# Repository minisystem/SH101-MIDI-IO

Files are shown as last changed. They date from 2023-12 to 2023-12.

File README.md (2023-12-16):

# SH101 MIDI IO
PCB assembly for TRS-DIN MIDI connections to SH-101

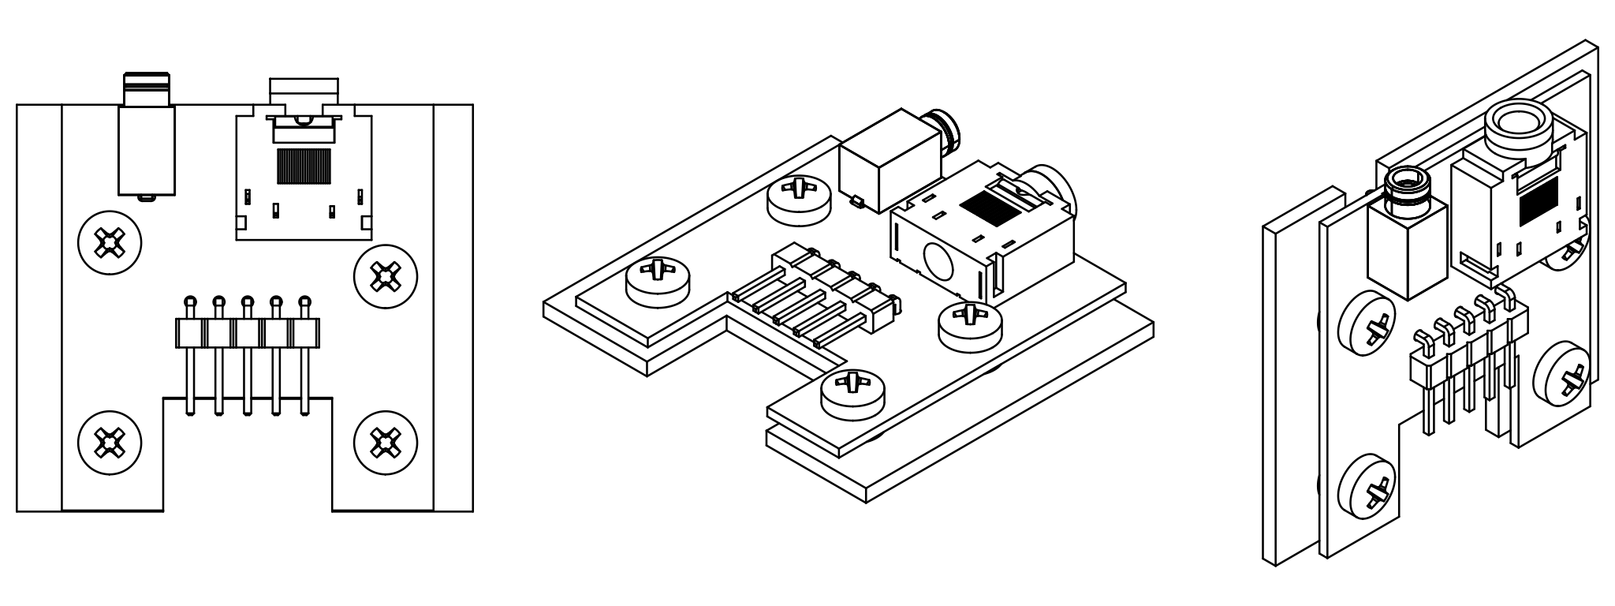
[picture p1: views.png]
pcb assembly


## Overview
[Tubbutec](https://tubbutec.de/sh-1oh1/) make an amazing upgrade kit for the Roland SH-101 that replaces the original CPU, adding MIDI, some new modulation sources, and an enhanced sequencer and arpeggiator. The kit comes with a pair of MIDI jacks that can be mounted by drilling holes in the enclosure, or concealed in the battery compartment. This respository contains the design files to build a TRS adapter board to replace the SH-101's MODULATION GRIP PCB, which allows the use of Type A TRS-MIDI cables. The MIDI IN uses the 3.5 MM jack and the MIDI OUT uses the 2.5 MM jack. To get the jacks to the right height, a PCB sandwich is required with 1.5 MM spacers. I used SMT M3 spacers, but a regular PCB spacer of the right height should work as well. There's enough room in the enclsoure to leave the original MODULATION GRIP PCB, so it does not need to be disconnected or removed. The jack PCB needs to be 1 MM thick, and the spacer PCB needs to be 1.6 MM thick.

The project was designed in Kicad 6.0. The BOM and pos files for PCBA of the modulation grip spacer PCB with SMT spacers have been formatted for the JLC PCBA service.

## BOM

| Part Ref | Description | Part No |
| --- | --- | --- |
| J1 | 3.5 MM JACK | CUI SJ1-3523N |
| J2 | 2.5 MM JACK | CUI SJ1-2503A |
| J3 | 5 POS HEADER | 0.100" RIGHT ANGLE |
| SM1-4 | 1.5 MM M3 SPACER | SMTSO3015CTJ |

You'll also need a Type A 3.5 MM TRS MIDI cable and a 2.5 MM TRS MIDI cable if you want access to MIDI OUT data. The 2.5 MM TRS to MIDI cable isn't as widely availabe, but is used by a lot of IK Multimedia iRig series products.

## PCBs

The PCB fabrication files are in the [gerbers](/gerbers/) folder. _SH101_IO.zip_ contains the gerber files for the 1 MM thick jack board and _SH101_MOD_GRIP_BOARD.zip_ contains the gerbers for the 1.6 MM modulation grip spacer board. 

## Assembly

Once assembled, the PCB sandwich slides into guide slots of the plastic enclosure. Tape the original modulation grip jack board to the side of the enclosure. Use a 5 conductor connector assembly, crimp contacts, 0.100" pitch (TE 5-103975-4 or equivalent). Refer to the schematic and PCB markings for wiring order.

The Type A TRS wiring is as follows:

MIDI 4 (source) > RING

MIDI 2 (shield) > SLEEVE

MIDI 5 (sink) > TIP

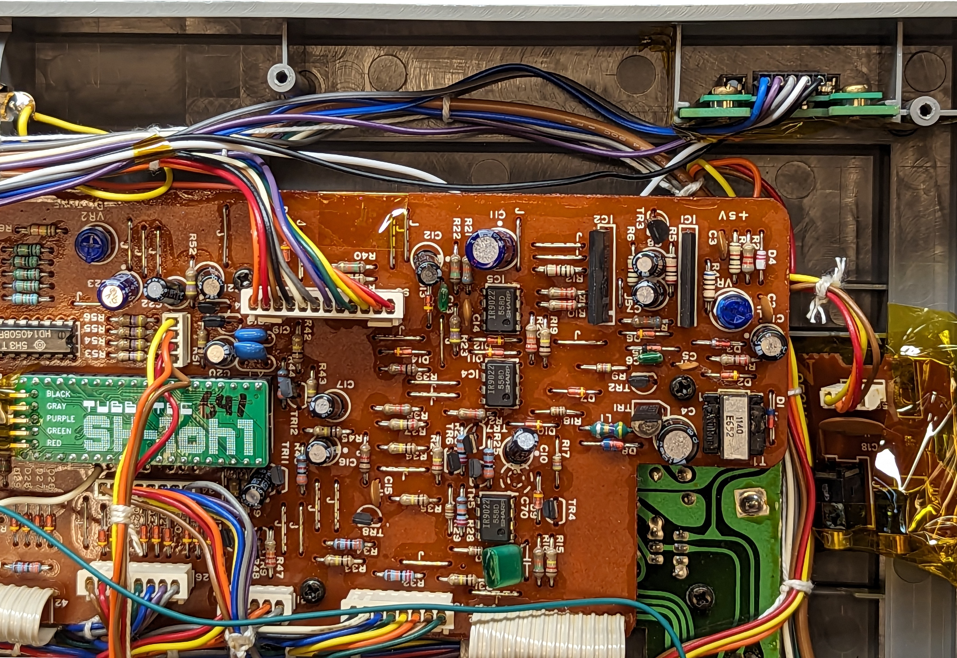
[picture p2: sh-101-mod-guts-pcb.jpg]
pcb guts


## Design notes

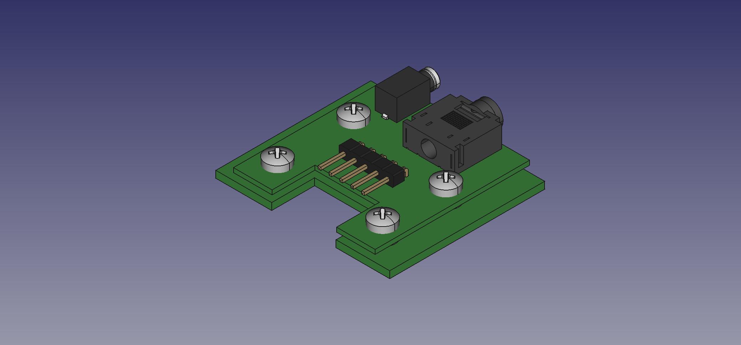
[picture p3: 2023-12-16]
3d/orthoview.jpeg

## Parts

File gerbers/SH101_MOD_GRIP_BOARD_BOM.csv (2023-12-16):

Comment | Designator | Footprint | LCSC
SMTSO3015CTJ | SP1,SP2,SP3,SP4 | MyModules:SMTSO3060CTJ | C2915632

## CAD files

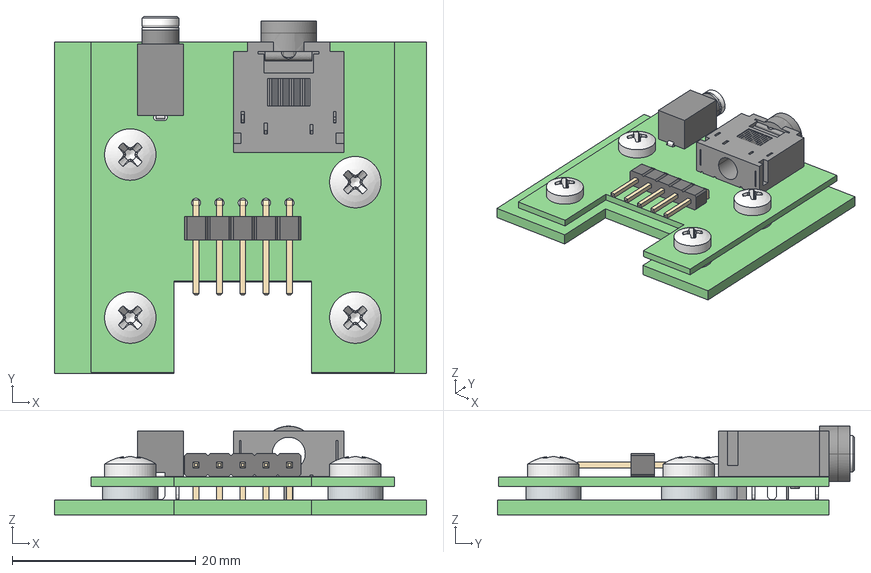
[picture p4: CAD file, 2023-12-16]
3d/assembly.step
40.5 x 38.9 x 9.66 mm
SH101_IO PCB
SH101_MOD_GRIP_BOARD PCB
M3x4-Screw
M3x4-Screw007
M3x4-Screw005
M3x4-Screw006

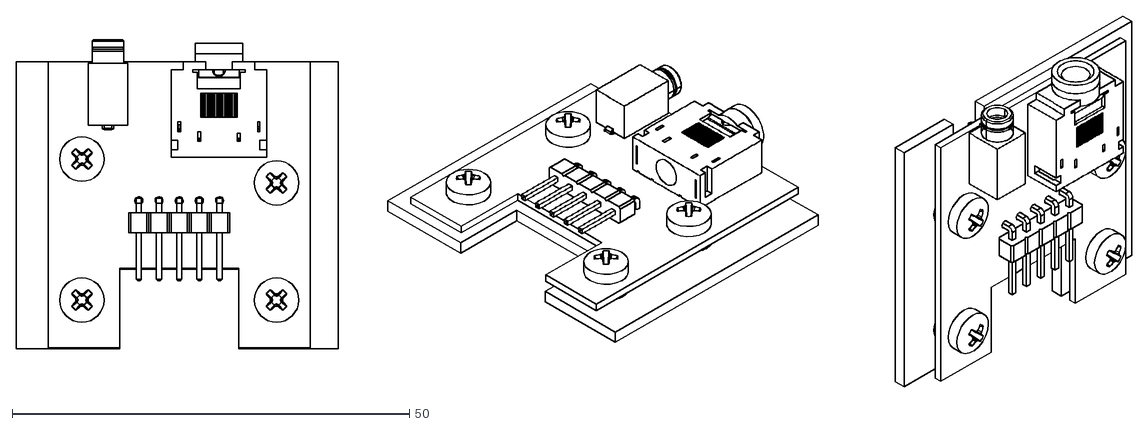
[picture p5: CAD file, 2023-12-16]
3d/views.dxf
140.4 x 46.7

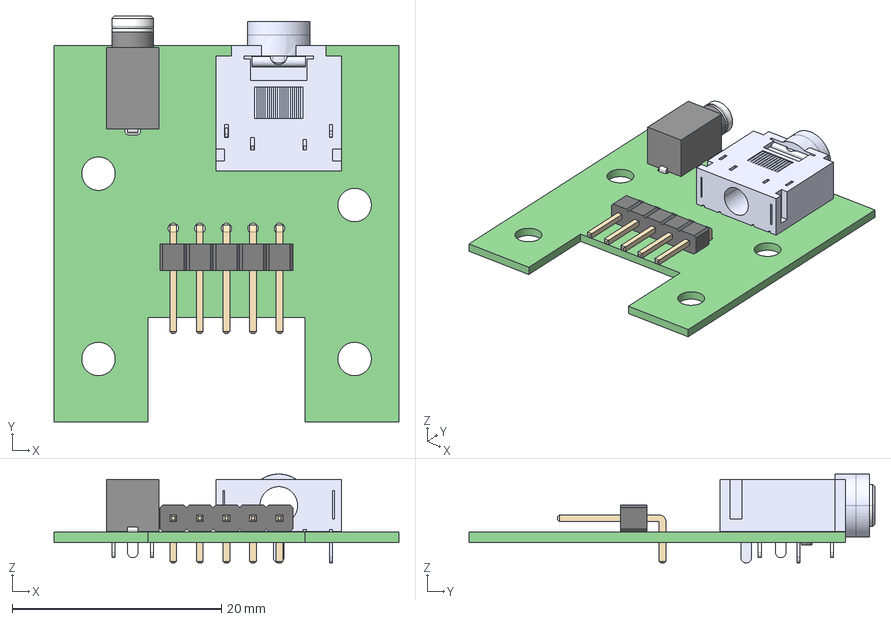
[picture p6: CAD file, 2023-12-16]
3d/SH101_IO.step
33.0 x 38.8 x 8.51 mm
SH101_IO PCB

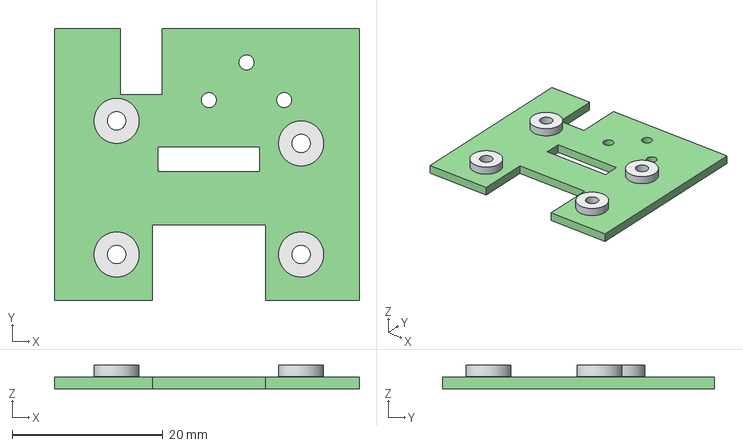
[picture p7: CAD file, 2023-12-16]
3d/SH101_MOD_GRIP_BOARD.step
40.5 x 36.1 x 3.15 mm
SH101_MOD_GRIP_BOARD PCB

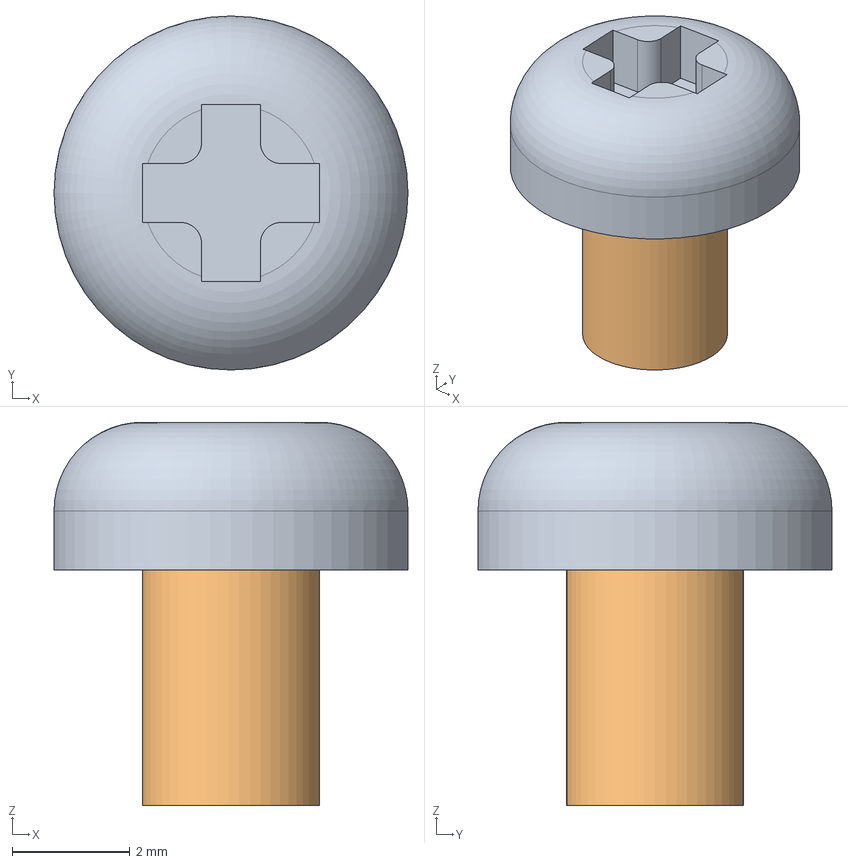
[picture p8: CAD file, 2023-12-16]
3d/M3x4MM.FCStd
6.00 x 6.00 x 6.50 mm

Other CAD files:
3d/SH101_IO_MOD_GRIP_BOARD.FCStd

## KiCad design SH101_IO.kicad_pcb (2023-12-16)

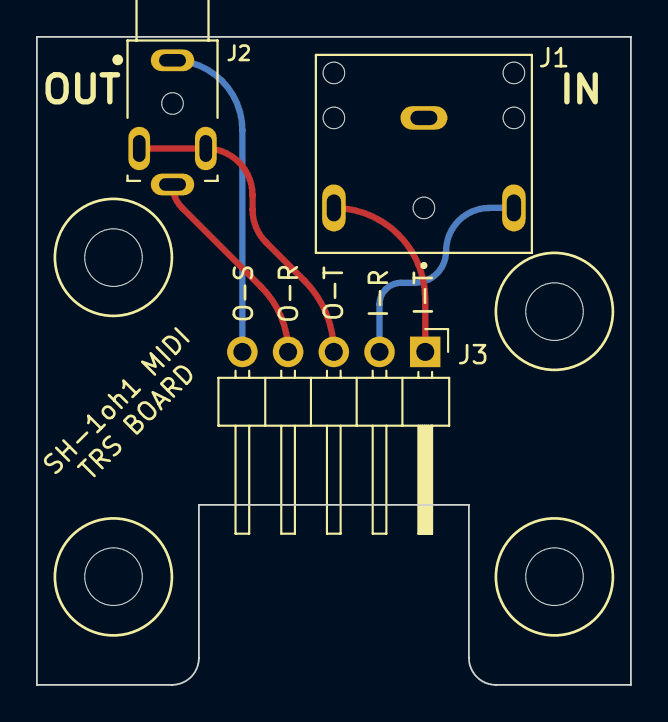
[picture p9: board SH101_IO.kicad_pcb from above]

Board: 2 copper layers, 33.0 x 36.0 mm, 3 parts (0 on the bottom side), 5 nets.

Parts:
J1: AudioJack3; CUI_SJ1-3523N
J2: AudioJack3; CUI_SJ1-2503A
J3: Conn_01x05_Male; PinHeader_1x05_P2.54mm_Horizontal

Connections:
unnamed: J1.R, J3.2
unnamed: J1.T, J3.1
unnamed: J2.R, J3.4
unnamed: J2.S, J3.5
unnamed: J2.T, J3.3

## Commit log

2023-12-16 added pcb photo
2023-12-16 cleanup 3d files
    [M3x4MM.FCStd, SH101_IO.step, SH101_IO_MOD_GRIP_BOARD.FCStd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]
2023-12-16 added drawing views
    [assembly.step, views.dxf]
